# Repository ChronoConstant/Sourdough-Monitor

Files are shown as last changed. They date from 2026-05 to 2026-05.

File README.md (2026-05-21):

# Sourdough Monitor

A small battery-powered device that watches a sourdough starter rise after
feeding and reports to Home Assistant. It measures the height of the starter
with a time-of-flight sensor, tracks temperature and humidity, and lets you
mark feedings with a button press — so you can see, from your phone or a wall
dashboard, exactly how far along your starter is and when it peaked.

Built on a Seeed XIAO ESP32-C3 running [ESPHome](https://esphome.io/),
publishing over MQTT. Fair warning... I am dumb, Claude built most of this. So please take everything with a grain of LLM flavored salt. 

One small note about the enclosure. Obviously thats designed for a specific jar (Brod and Taylor) so it may or may not fit your project. Also I forgot to put a hole in it for a button. I drilled a hole for my button because I'm janky and didn't want to print it again. I'll update that eventually.

<!-- Add a photo of your build here, e.g.:
![Sourdough Monitor](docs/images/prototype.jpg)
-->

## What it does

- **Measures starter height** with a VL53L4CD time-of-flight sensor aimed down
  into the jar from a lid-mounted enclosure.
- **Tracks the fermentation environment** — temperature and humidity from an
  SHT31-D.
- **Computes rise %** relative to the post-feed baseline, and tracks the
  maximum rise reached in the current cycle.
- **"Just Fed" button** — a press marks a new feed cycle: it archives the
  previous cycle's stats, resets tracking, and re-establishes the baseline.
  Mirrored as a Home Assistant button so you can also trigger it from a phone.
- **Runs for weeks on a battery** — deep sleep between readings gets roughly a
  month per charge on a 1200 mAh LiPo.
- **Home Assistant integration** — all values auto-discover over MQTT. Includes
  a ready-made dashboard card and a peak-detection sensor.

## How it works

```
[SHT31-D]  temp/humidity ──┐
                           ├── I²C ── [XIAO ESP32-C3] ── Wi-Fi ── MQTT ── [Home Assistant]
[VL53L4CD] distance ───────┤
[Push button] "Just Fed" ──┘
```

The ESP32-C3 wakes every ~15 minutes, takes a reading, publishes it over MQTT,
and goes back to deep sleep. A button press also wakes it. Home Assistant
receives the data via MQTT discovery — entities appear automatically, no manual
HA configuration of the sensors required.

**Rise tracking**: when you long press (because the button wakes the board it requires a 2 second or so press to allow time for the board to wake up and realized you're pressing the button) "Just Fed", the firmware discards the old
baseline. The next sensor reading becomes the new baseline; subsequent readings
update it downward if the starter settles further. Once the starter starts
rising, the baseline locks and rise % is measured against it. This adaptive
approach means there's no fixed "settling delay" to guess at — the baseline
naturally finds the low point of the cycle.

## Bill of materials

| Part | Notes |
|---|---|
| **Seeed Studio XIAO ESP32-C3** | The MCU. Other ESP32-C3 boards can work but the pin map and the build guide assume the XIAO. |
| **VL53L4CD** time-of-flight sensor breakout | I²C. Measures the starter surface. A VL53L1X breakout also works — the driver supports both. |
| **SHT31-D** temperature/humidity breakout | I²C. Generic "SHT3x" breakouts work; see the troubleshooting doc re: the ADDR pin. |
| **Momentary push button** | Panel-mount, ~12 mm. The "Just Fed" input. |
| **LiPo battery, ~1200 mAh** | Single cell, 3.7 V, with a JST connector I snipped off to allow me to solder it to the board. The XIAO has onboard charging. |
| **2 × 100 kΩ resistors** | Optional — for the battery-voltage divider. Skip if you don't want battery monitoring. |
| **26–28 AWG wire** | Silicone-jacketed is easiest to work with. |
| **Tall straight-sided jar** | Weck / deli-quart style. Straight walls keep the rise math simple. |
| **3D-printed lid enclosure** | Holds everything; ToF aims down through a hole in the center. See [`enclosure/`](enclosure/). |

## Repository layout

```
.
├── README.md                  — this file
├── BUILD.md                   — step-by-step build & setup guide
├── LICENSE                    — GPLv3 (see "License" below)
├── firmware/
│   ├── sourdough.yaml          — the main ESPHome firmware
│   ├── sourdough-scan.yaml     — minimal I²C scanner for first bring-up
│   ├── secrets.yaml.example    — config template (copy to secrets.yaml)
│   └── components/vl53l1x/     — bundled ToF driver (third-party, see NOTICE)
├── homeassistant/
│   ├── lovelace-card.yaml      — dashboard card
│   └── peak-detection.yaml     — past-peak binary sensor + notification
├── enclosure/                  — 3D-printable lid STL files
└── docs/
    ├── wiring.md               — wiring guide
    └── troubleshooting.md      — common issues and fixes
```

## Quick start

Full instructions are in **[BUILD.md](BUILD.md)**. In short:

1. Wire the two I²C sensors and the button to the XIAO (see [`docs/wiring.md`](docs/wiring.md)).
2. Install [ESPHome](https://esphome.io/), copy `firmware/secrets.yaml.example`
   to `firmware/secrets.yaml`, and fill in your Wi-Fi and MQTT details.
3. Flash `firmware/sourdough.yaml` to the XIAO over USB.
4. The device's entities auto-appear in Home Assistant via MQTT discovery.
5. Calibrate the empty-jar distance, add the dashboard card, and you're done.

**Prerequisites**: Home Assistant with an MQTT broker (the Mosquitto add-on is
the usual choice).

## Home Assistant integration

Entities auto-discovered over MQTT include temperature, humidity, ToF distance,
starter height, rise %, max rise % this cycle, hours since feed, a battery
level, and the "Just Fed" button.

- [`homeassistant/lovelace-card.yaml`](homeassistant/lovelace-card.yaml) — a
  compact dashboard card (uses Mushroom + mini-graph-card from HACS).
- [`homeassistant/peak-detection.yaml`](homeassistant/peak-detection.yaml) — a
  template binary sensor that flips on when the starter has come off its peak,
  plus an example notification automation.

## Battery life

With deep sleep and a 15-minute wake interval, the device averages well under a
milliamp and runs roughly (hopefully?) **a month per charge** on a 1200 mAh LiPo. Charging is
over the XIAO's USB-C port. The optional resistor divider lets Home Assistant
display a battery percentage.

## Attribution

The VL53L4CD/VL53L1X driver in `firmware/components/vl53l1x/` is third-party
code from [Averyy/esphome-custom-components](https://github.com/Averyy/esphome-custom-components),
MIT licensed. It is bundled here (with a small i2c-API compatibility patch) so
the firmware builds reproducibly. See
[`firmware/components/vl53l1x/NOTICE`](firmware/components/vl53l1x/NOTICE) for
details of what was changed and why.

This project was developed with substantial help from Claude (Anthropic's AI
assistant) — firmware, and documentation.

## License

This project is licensed under the **GNU General Public License v3.0**. See the
`LICENSE` file. In short: you're free to use, modify, and distribute it, but
distributed derivatives must also be open-sourced under GPLv3.

The bundled `vl53l1x` component retains its original MIT license, which applies
to the files in that directory only. MIT is compatible with GPLv3.

## Contributing

Issues and pull requests welcome. If you build one, a photo and notes on what
you'd change are always appreciated.

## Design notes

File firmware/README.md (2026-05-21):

# firmware/

ESPHome firmware for the Sourdough Monitor.

| File | Purpose |
|---|---|
| `sourdough.yaml` | The main firmware — sensors, just-fed logic, deep sleep, MQTT. |
| `sourdough-scan.yaml` | Minimal I²C scanner. Flash first to verify sensor wiring. |
| `secrets.yaml.example` | Config template. Copy to `secrets.yaml` and fill in your values. |
| `components/vl53l1x/` | Bundled third-party ToF driver — see `components/vl53l1x/NOTICE`. |

**Full setup instructions — wiring, flashing, calibration, Home Assistant — are
in [`../BUILD.md`](../BUILD.md).**

Quick reference:

```bash
cp secrets.yaml.example secrets.yaml   # then edit secrets.yaml
esphome run sourdough-scan.yaml        # verify sensors respond on I²C
esphome run sourdough.yaml             # flash the real firmware
```

The first flash must be over USB; after that, `esphome run` updates over the
air. If the USB upload won't connect, put the XIAO in download mode: hold **B**,
tap **R**, release **B**, retry. More in
[`../docs/troubleshooting.md`](../docs/troubleshooting.md).

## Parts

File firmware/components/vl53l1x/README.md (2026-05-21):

# VL53L1X Component for ESPHome

This component provides integration with the VL53L1X/VL53L4CD Time-of-Flight (ToF) distance sensor for ESPHome using I2C. This implementation is an adaptation of existing open-source code that has been modified to enhance functionality and compatibility with ESPHome.

## Features

-   Supports both VL53L1X and VL53L4CD sensors
-   I2C communication
-   Configurable distance mode (short/long)
-   Configurable update interval
-   Range status reporting
-   Automatic sensor initialization and configuration

## Hardware Setup

Connect your VL53L1X/VL53L4CD sensor to your ESP32/ESP8266 using the following pins:

-   VL53L1X VCC → ESP32 3.3V
-   VL53L1X GND → ESP32 GND
-   VL53L1X SDA → ESP32 SDA (GPIO21 in example)
-   VL53L1X SCL → ESP32 SCL (GPIO22 in example)
-   VL53L1X XSHUT → ESP32 GPIO (GPIO23 in example, optional for power control)

## Configuration Variables

-   **distance_mode** (_Optional_, string, default: "long"): The distance mode of the sensor. Options are "short" or "long". Note that VL53L4CD sensors only support "short" mode and will be automatically configured as such.
-   **update_interval** (_Optional_, time, default: 0.5s): How often to update the sensor readings.
-   **i2c_id** (_Optional_, ID): The ID of the I2C bus if you have multiple I2C buses.

## Sensor Outputs

-   **distance**: Distance measurement in millimeters
-   **range_status**: Status of the range measurement (0 = valid, 1-4 = various error states), but I personally haven't gotten these to show up or be helpful

## Basic Configuration

```yaml
i2c:
    sda: GPIO21
    scl: GPIO22
    scan: true

# Optional XSHUT pin control
output:
    - platform: gpio
      pin: GPIO23
      id: xshut_pin

# Power on sequence
esphome:
    on_boot:
        then:
            - output.turn_on: xshut_pin
            - delay: 1s # Allow VL53L1X to boot (min 1.2ms required)
    on_shutdown:
        then:
            - output.turn_off: xshut_pin

vl53l1x:
    distance_mode: long
    update_interval: 0.5s

sensor:
    - platform: vl53l1x
      distance:
          name: "VL53L1X Distance"
          id: tof_distance
      range_status:
          name: "VL53L1X Range Status"
```

## Filtering Example

This example shows how to filter out invalid readings and apply a median filter to stabilize measurements:

```yaml
sensor:
    - platform: vl53l1x
      distance:
          name: "VL53L1X Distance"
          filters:
              - lambda: |-
                    if (x < 45 || x > 4200 || x == 0.0 || std::isnan(x)) {
                      return 0;
                    }
                    return x;
              - median:
                    window_size: 5
                    send_every: 5
                    send_first_at: 1
```

## Installation

There are two ways to install this component:

### Option 1: Direct from GitHub (Recommended)

Add the following to your ESPHome configuration:

```yaml
external_components:
    - source: github://Averyy/esphome-custom-components
      components: [vl53l1x]
```

**Note:** Using the GitHub repository version means you'll automatically get updates, but it could change at any moment. If stability is critical for your project, consider using the local installation method.

### Option 2: Local Installation

If you prefer a more stable setup or need to modify the component:

1. Create a `components` directory in your ESPHome configuration directory
2. Copy the `vl53l1x` directory into the `components` directory
3. Add the `external_components` section to your YAML configuration:

```yaml
external_components:
    - source: components
```

## Notes

-   The VL53L1X component automatically detects and configures the sensor on startup
-   The VL53L4CD sensor is automatically detected and forced to use "short" distance mode
-   The timing budget is set to 500ms for maximum accuracy
-   The sensor has a practical range of approximately 45mm to 4000mm
-   Readings outside this range or with invalid status should be filtered out
-   The sensor updates approximately every 90ms internally, regardless of the configured update interval

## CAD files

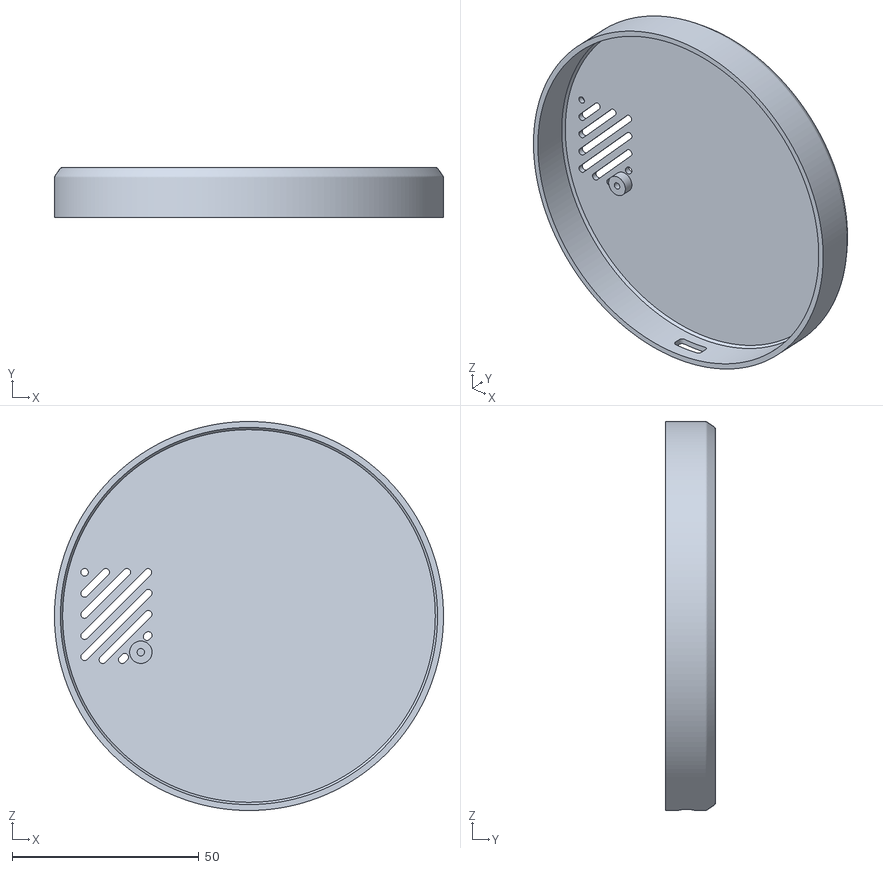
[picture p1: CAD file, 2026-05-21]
enclosure/Sourdough Lid Cover.stl
104.1 x 13.5 x 104.1

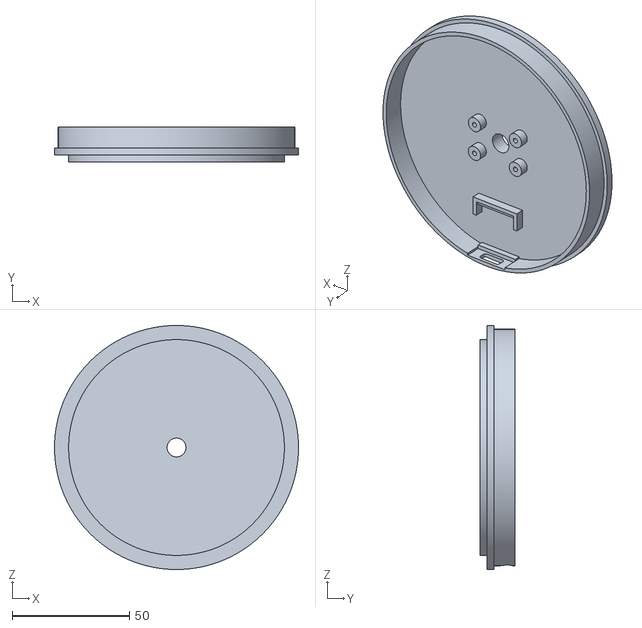
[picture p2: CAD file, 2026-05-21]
enclosure/Sourdough Lid Proto v2.stl
104.1 x 15.0 x 104.1

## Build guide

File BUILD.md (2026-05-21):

# Build Guide

Step-by-step instructions to build and set up a Sourdough Monitor. Plan on an
afternoon for the electronics and first flash, plus printing time for the
enclosure.

If something goes wrong, check [`docs/troubleshooting.md`](docs/troubleshooting.md)
first — most of the common snags are documented there with fixes.

---

## Before you start

You'll need:

- The parts in the [bill of materials](README.md#bill-of-materials).
- A **Home Assistant** instance with an **MQTT broker**. The
  [Mosquitto add-on](https://www.home-assistant.io/integrations/mqtt/) is the
  standard choice. If you don't have MQTT set up yet, do that first — the
  device has nowhere to publish to without it.
- A computer to run **ESPHome** (Windows, macOS, or Linux). The build guide
  uses the ESPHome command line.
- A **USB-C data cable** (not a charge-only cable) for the first flash.
- Basic soldering tools.

A note on skill level: this is an intermediate project. You don't need to be an
electronics expert, but you should be comfortable soldering small wires and
editing a YAML text file.

---

## Step 1 — Wiring

Full pin-by-pin detail is in [`docs/wiring.md`](docs/wiring.md). Summary:

| Connection | XIAO ESP32-C3 pin |
|---|---|
| Both sensors: VIN | `3V3` |
| Both sensors: GND | `GND` |
| Both sensors: SDA | `D4` (GPIO 6) |
| Both sensors: SCL | `D5` (GPIO 7) |
| Push button (one leg) | `D1` (GPIO 3) |
| Push button (other leg) | `GND` |
| LiPo battery | `BAT+` / `BAT−` pads (underside) |

Both I²C sensors share the same SDA and SCL wires — they have different
addresses (`0x44` and `0x29`) so they coexist on one bus. Most sensor breakouts
include their own pull-up resistors; don't add more.

For the **optional battery monitor**, wire a voltage divider — two 100 kΩ
resistors in series between `BAT+` and `GND`, with the midpoint going to
`D2` (GPIO 4). See Step 9.

**Tip**: before committing to soldered connections, build it on a breadboard
and confirm both sensors respond (Step 4). It's much easier to fix a wiring
mistake before everything is soldered into an enclosure.

---

## Step 2 — Install ESPHome

ESPHome needs **Python 3.10 or newer**. Check with `python3 --version`.

Install ESPHome (pipx keeps it cleanly isolated):

```bash
pip install pipx       # if you don't have pipx
pipx install esphome
```

Or with plain pip: `pip install esphome`.

Confirm it works: `esphome version`. You want a current release — if it
installs something old (2025.x or earlier), your Python is probably too old;
see [troubleshooting](docs/troubleshooting.md#esphome-installs-an-old-version).

---

## Step 3 — Configure your secrets

The firmware reads Wi-Fi and MQTT settings from a `secrets.yaml` file that you
create from the template.

```bash
cd firmware
cp secrets.yaml.example secrets.yaml
```

Open `secrets.yaml` and fill in your values. The file is commented with what
each one means. At minimum you need `wifi_ssid`, `wifi_password`,
`mqtt_broker`, and `ota_password`. Notes:

- The ESP32-C3 only does **2.4 GHz Wi-Fi** — it cannot see a 5 GHz network.
- The Wi-Fi SSID is **case-sensitive**.
- `mqtt_broker` is just the IP/hostname — **no `:1883` port suffix**.
- If your broker requires a login, set `mqtt_username` / `mqtt_password`. If
  it's anonymous, set them to empty strings (`""`).

### Optional: static IP

By default the device uses DHCP, which works on any network with zero extra
configuration — you can skip this entirely.

If you'd like a small battery-life improvement, you can give the device a
static IP. It saves the ~1–2 seconds of DHCP negotiation on every deep-sleep
wake. To enable it:

1. In `firmware/sourdough.yaml`, find the `wifi:` block and **uncomment the
   `manual_ip:` block** (remove the leading `#` from those five lines).
2. In `secrets.yaml`, **uncomment and fill in** the `static_ip`, `gateway`,
   `subnet`, and `dns1` values.
3. For `static_ip`, pick an address that's **outside your router's DHCP pool**
   (check the router's DHCP range), or reserve the address in your router by
   the device's MAC. This avoids the static IP colliding with an address the
   router might hand out to something else.
4. `gateway` is your router's IP, `subnet` is almost always `255.255.255.0`,
   and `dns1` is usually your router's IP.

Do this before flashing (Step 5). If you set it up later, just re-flash. And if
the device ever fails to connect after enabling it, the values almost certainly
don't match your network — comment the `manual_ip:` block back out to fall back
to DHCP.

---

## Step 4 — Verify the sensors (I²C scan)

Before flashing the full firmware, flash the minimal scanner config. This just
brings up the I²C bus and prints what it finds — a quick sanity check that your
wiring is correct.

```bash
esphome run sourdough-scan.yaml
```

For the **first flash you must use USB** (there's no firmware on the chip yet
for an over-the-air update). When prompted, choose the USB/serial device.

**macOS / Windows users**: if the upload fails to connect, you need to put the
XIAO into download mode manually — hold the **B** (Boot) button, tap **R**
(Reset), release **B**, then immediately retry. See
[troubleshooting](docs/troubleshooting.md#flashing-fails-to-connect-over-usb).

In the log output, you're looking for **both** sensor addresses:

```
Found i2c device at address 0x29   ← VL53L4CD
Found i2c device at address 0x44   ← SHT31-D
```

If only one shows up, fix the wiring before going further — the
[troubleshooting doc](docs/troubleshooting.md#only-one-i2c-sensor-shows-up) has
a checklist.

---

## Step 5 — Flash the firmware

Once both sensors scan cleanly, flash the real firmware:

```bash
esphome run sourdough.yaml
```

Same as before — USB for this first flash, BOOT/RESET dance if it won't
connect. The compile takes a few minutes the first time (it downloads
toolchains and builds the bundled component).

After this first USB flash, **future updates can be done wirelessly** — run the
same command and pick the network/OTA option.

> **Path gotcha**: ESP-IDF cannot build from a path containing spaces. If your
> project folder has spaces in its name, the build fails with "Detected a
> whitespace character in project paths." Rename the folder to use underscores
> or dashes. (See [troubleshooting](docs/troubleshooting.md#build-fails-on-whitespace-in-path).)

---

## Step 6 — Confirm entities in Home Assistant

The firmware publishes over MQTT with discovery enabled, so Home Assistant
picks up the device automatically. Within a minute or two of the device's first
boot, go to **Settings → Devices & Services → MQTT** and you should see a
"Sourdough Monitor" device with entities: Temperature, Humidity, ToF Distance,
Starter Height, Rise %, Max Rise % This Cycle, Hours Since Feed, Battery
Voltage / Level, and a "Just Fed" button.

If nothing appears, check the device log (`esphome logs sourdough.yaml`) for
the Wi-Fi and MQTT connection lines.

---

## Step 7 — Calibrate the empty-jar distance

The firmware needs to know the distance from the sensor down to the bottom of
the empty jar (`d_empty`) to compute starter height.

1. Put a small piece of **white paper** flat in the bottom of the **empty**
   jar. (Glass and clear plastic can be partly transparent to the sensor's
   infrared — the paper gives it a clean surface to range against.)
2. Put the lid/enclosure on the jar in its normal position.
3. Watch the **ToF Distance** entity in Home Assistant. Let it report a few
   readings and note the stable value (in mm).
4. In Home Assistant, find the **Empty Jar Distance (mm)** number entity and
   set it to that value.

That's it. The starter-height and rise-% math now have their reference point.
If you ever change how the lid sits on the jar or use a new jar, redo this.

---

## Step 8 — Add the dashboard card

[`homeassistant/lovelace-card.yaml`](homeassistant/lovelace-card.yaml) is a
compact card for a Home Assistant dashboard. It uses two cards from
[HACS](https://hacs.xyz/): **Mushroom** and **mini-graph-card** — install those
first.

Then, on a dashboard: **Edit → Add Card → Manual**, and paste in the contents
of `lovelace-card.yaml`. If your device entities have different IDs than the
defaults, adjust the entity names in the card (they're all near the top of each
section).

---

## Step 9 — Battery monitoring (optional)

If you wired the voltage divider (Step 1), the **Battery Voltage** and
**Battery Level** entities will show real values. If you didn't, those entities
just report nonsense — harmless, ignore them or remove the `adc` and battery
`template` sensors from `sourdough.yaml`.

To verify the divider: with the device powered, measure between `D2` (GPIO 4)
and `GND` — it should read about half the battery voltage.

---

## Step 10 — Peak detection (optional)

[`homeassistant/peak-detection.yaml`](homeassistant/peak-detection.yaml)
contains a Home Assistant template binary sensor that flips on when the starter
has come off its peak, plus an example notification automation. The file is
commented with where each piece goes in your HA config and what to tune. It's
optional — the monitor is fully usable without it.

---

## Using it day to day

**To mark a feeding**: Push the button before removing the lid to avoid a crazy reading when you set it aside. feed the starter, put the lid back on the jar, and
press the button. (If the device is asleep, hold the button for about a second or two
so the press registers as it wakes up.)

What happens: the previous cycle's stats get archived, rise tracking resets, and
"Rise %" shows 0 until the next sensor reading establishes the new
baseline — up to ~15 minutes later. After that, watch the rise climb.

**Charging**: plug a USB-C cable into the XIAO. With deep sleep the battery
lasts about a month, so this is infrequent.

---

## Updating the firmware later

After the first USB flash, the device accepts over-the-air updates. Edit
`sourdough.yaml`, then:

```bash
esphome run sourdough.yaml
```

Choose the network/OTA option when prompted.

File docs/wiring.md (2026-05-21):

# Wiring

**Board:** Seeed XIAO ESP32-C3.

## Pin assignments

| XIAO pin | GPIO | Role | Notes |
|---|---|---|---|
| D4 (SDA) | GPIO 6 | I²C SDA | Silkscreen-labeled SDA; clean GPIO (not strapping, not USB, not flash) |
| D5 (SCL) | GPIO 7 | I²C SCL | Silkscreen-labeled SCL |
| D1 | GPIO 3 | Push button | Active low, internal pull-up enabled in firmware |
| D2 | GPIO 4 | Battery ADC (optional) | Reads the midpoint of the BAT+/GND voltage divider; see [Battery monitoring](#battery-monitoring-optional) |
| 3V3 | — | Sensor power | Do NOT use the 5V pin — both sensors run fine at 3.3 V |
| GND | — | Common ground | |

Free for later use: D0 (GPIO 2, strapping — OK as output), D3 (GPIO 5), D6 (GPIO 21, UART TX), D7 (GPIO 20, UART RX), D8 (GPIO 8, strapping), D10 (GPIO 10). **Avoid** D9 (GPIO 9) — that's the BOOT strapping pin.

## Why these pins
- **SDA/SCL on D4/D5** — matches the XIAO silkscreen, keeps documentation honest, and both are clean GPIOs with no special-function conflicts.
- **Button on D1** — any "safe" GPIO works; D1 puts it adjacent to the GND pin on the header for a clean two-wire run.
- **Battery sense on D2** — must be an ADC-capable pin; the ESP32-C3's ADC1 channels are on GPIO 0–4, and D2/GPIO 4 is otherwise free.

## Sensor hookup

Both breakouts (Adafruit/SparkFun-style; verify your specific boards):

| SHT31-D pin | VL53L4CD pin | XIAO pin |
|---|---|---|
| Vin / 3V | Vin / VCC | 3V3 |
| GND | GND | GND |
| SDA | SDA | D4 (GPIO 6) |
| SCL | SCL | D5 (GPIO 7) |

Sensor SDA lines share a single wire; sensor SCL lines share a single wire. The two breakouts have different I²C addresses (`0x44` and `0x29`) so they don't collide on the shared bus. Both breakouts include onboard 10 kΩ pull-ups — **don't add extras**; two in parallel already gives ~5 kΩ, which is on the strong side.

## Battery monitoring (optional)

The XIAO's ADC can't read the LiPo voltage directly — a charged cell sits above
the 3.3 V the ADC can measure, and there's no internal divider on the board. To
monitor the battery, add an external voltage divider: two equal resistors
between BAT+ and GND, with the midpoint feeding an ADC pin.

```
BAT+ ──┬── 100 kΩ ──┬── 100 kΩ ── GND
       │            │
   (battery)        └── to D2 (GPIO 4)
```

The midpoint sits at half the battery voltage — roughly 1.9 V at a 3.7 V cell,
2.1 V at a full 4.2 V — comfortably inside the ADC's range. The firmware doubles
the reading back to actual battery voltage and estimates a percentage from it.

Notes:
- **100 kΩ each** is the recommended value. The divider draws current
  continuously (battery voltage ÷ 200 kΩ ≈ 19 µA) — negligible. Much lower
  values waste battery; much higher values make the ADC reading noisy.
- The bottom resistor can connect to GND or directly to the LiPo's BAT−
  terminal — they're the same node.
- This is **optional**. Skip it and the firmware's battery sensors just report
  meaningless values, which is harmless — ignore or delete those entities.

## Breadboard layout

```
        XIAO ESP32-C3
        ┌─────────────┐
USB-C ─→│             │
        │  5V         │
        │  GND ───────┼──── breadboard GND rail
        │  3V3 ───────┼──── breadboard 3V3 rail
        │  D0/GPIO2   │
        │  D1/GPIO3 ──┼──── button ── GND
        │  D2/GPIO4 ──┼──── battery divider midpoint (optional)
        │  D3/GPIO5   │
        │  D4/GPIO6 ──┼──── SDA bus ──── SHT31-D SDA, VL53L4CD SDA
        │  D5/GPIO7 ──┼──── SCL bus ──── SHT31-D SCL, VL53L4CD SCL
        │  D6/GPIO21  │
        │  D7/GPIO20  │
        │  D8/GPIO8   │
        │  D9/GPIO9   │  ← avoid (BOOT strapping)
        │  D10/GPIO10 │
        └─────────────┘

SHT31-D:   Vin→3V3 rail, GND→GND rail, SDA→SDA bus, SCL→SCL bus
VL53L4CD:  Vin→3V3 rail, GND→GND rail, SDA→SDA bus, SCL→SCL bus
Button:    one leg → D1, other leg → GND   (firmware enables INPUT_PULLUP)
Battery:   BAT+ → 100kΩ → D2 → 100kΩ → GND   (optional; see Battery monitoring)
```

## Power notes

- USB-C from the XIAO powers the device and charges the LiPo.
- The LiPo solders to the BAT+ / BAT− pads on the XIAO's underside. The XIAO has onboard charge management — plug in USB to charge, run on battery when unplugged.
- Wi-Fi antenna is integrated. A U.FL connector is available for an external antenna if Wi-Fi signal is weak where the device lives.

## After wiring: the I²C scan

Before flashing the full firmware, flash the minimal `sourdough-scan.yaml` config (just the `i2c:` block with `scan: true`). The boot log should list two devices:

```
[I][i2c.idf:170]: Found i2c device at address 0x29   ← VL53L4CD
[I][i2c.idf:170]: Found i2c device at address 0x44   ← SHT31-D
```

If you see only one address, the most likely culprits, in order:
1. A loose wire on SDA or SCL to the missing sensor.
2. The missing sensor's Vin is not actually getting 3.3 V (check with a multimeter against GND).
3. SDA/SCL swapped at one of the breakouts.
4. (Rare) the breakout has a non-default ADDR jumper soldered, putting the sensor on `0x45` or `0x52` instead. Reflow if so.

Once both addresses scan cleanly, the wiring is verified — flash the full firmware (`sourdough.yaml`).

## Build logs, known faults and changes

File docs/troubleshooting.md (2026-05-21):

# Troubleshooting

Every issue here was hit during the development of this project. If you run
into something, there's a decent chance the answer is below.

---

## Sensors and wiring

### Only one I2C sensor shows up

The I²C scan finds one address but not the other (you want both `0x29` for the
VL53L4CD and `0x44` for the SHT31-D).

Check, in order:

1. **A loose wire** to the missing sensor — SDA, SCL, VIN, or GND. With the
   device powered, measure each pin on the missing sensor's breakout against
   GND: VIN should read ~3.3 V, SDA and SCL should idle near 3.3 V.
2. **SDA/SCL swapped** at the missing breakout.
3. **The chip is simply dead.** Cheap sensor breakouts have a high failure
   rate. Also sometimes you might get a counterfeit off amazon. If power, ground, and both bus lines measure correct at the breakout
   and it still doesn't answer at any address, replace it. (This happened to
   me — the first SHT31-D was dead on arrival despite perfect wiring.)

---

## ESPHome and flashing

### `vl53l4cd` / `vl53l1x` platform not found

The VL53L4CD is **not in ESPHome core**. This project bundles a working driver
in `firmware/components/vl53l1x/` and the firmware references it via a local
`external_components` entry — so a normal build just works.

If you ever swap in the upstream component fresh from
[Averyy/esphome-custom-components](https://github.com/Averyy/esphome-custom-components)
and the build fails with errors like *"candidate expects 3 arguments, 4
provided"* on `write_register16` / `read_register16` — that's an ESPHome i2c
API change the upstream hasn't caught up with. The fix is the patch already
applied to the bundled copy: remove the 4th argument (a `true`/`false`) from
those five calls. See `firmware/components/vl53l1x/NOTICE`.

### ESPHome installs an old version

If `esphome version` reports an old release (2025.x or earlier), your Python is
too old. ESPHome needs **Python 3.10+**; older Python silently pins ESPHome to
its last compatible release. Check `python3 --version`. On macOS the system
Python is often 3.9 — install a newer one (e.g. `brew install python@3.12`) and
reinstall ESPHome.

### Build fails on whitespace in path

Error: *"Detected a whitespace character in project paths."* ESP-IDF's build
system cannot handle spaces anywhere in the path to the project. Rename the
project folder (and any parent folders) to use underscores or dashes instead
of spaces, then rebuild.

### Flashing fails to connect over USB

Symptom: `Failed to connect to ESP32-C3: Wrong boot mode detected` or the
upload just times out. macOS especially struggles to auto-reset the XIAO into
download mode.

Fix — put the chip into download mode manually:

1. Hold down the **B** (Boot) button on the XIAO.
2. While holding B, tap the **R** (Reset) button and release it.
3. Release B.
4. Immediately re-run the flash command.

The chip is now in the ROM bootloader and esptool can connect reliably.

---

## Firmware behavior

### Rise % reads 0 for a while after a feed

Expected. After a "Just Fed" press the baseline is discarded; the next sensor
reading (up to one ~15-minute wake cycle away) establishes the new baseline.
Until then Rise % reads 0 — there is no baseline to measure against yet. Once
the new baseline is set, it starts climbing normally.

### Battery Voltage / Battery Level show nonsense

Those entities only mean something if you wired the optional voltage divider
(two 100 kΩ resistors, BAT+ → divider → GPIO 4 → GND). Without it, GPIO 4
floats and the readings are garbage. Either wire the divider or delete the
`adc` and battery `template` sensors from `sourdough.yaml`.

---

## Home Assistant

### Distance shows in inches instead of mm

Home Assistant auto-converts the display units of any sensor with a
`device_class` of `distance`, based on your account's unit system. This
firmware sets `device_class: ""` on the distance-type sensors specifically to
suppress that conversion. If you see inches anyway, confirm those `device_class:
""` lines are present, or switch your HA unit system to metric.

### Entities don't appear in Home Assistant

- Confirm the device actually connected to Wi-Fi and MQTT — check
  `esphome logs sourdough.yaml`.
- Confirm Home Assistant's MQTT integration is set up and pointed at the same
  broker.
- The MQTT discovery prefix must match (`homeassistant`, the default on both
  sides).

### Device shows "unavailable" in HA between readings

By default this firmware disables MQTT birth/will messages (see the `mqtt:`
block), specifically so HA does *not* mark everything unavailable each time the
chip sleeps. If you re-enable them, HA will flip every entity to "unavailable"
for the ~15 minutes between wakes. That's the trade-off — the device genuinely
is offline while asleep.

---

## Networking

### Device won't connect to Wi-Fi

- The ESP32-C3 is **2.4 GHz only**. It cannot see a 5 GHz network, even if your
  router shares one name across both bands (it'll just use the 2.4 GHz one — but
  confirm 2.4 GHz is enabled).
- The SSID is **case-sensitive**. `MyNetwork` and `mynetwork` are different
  networks. Copy it exactly.

### MQTT won't connect — "Couldn't resolve IP address"

The `mqtt_broker` value in `secrets.yaml` must be the address **only** — no
port. `192.168.1.10`, not `192.168.1.10:1883`. The port is configured
separately (and defaults to 1883).

### MQTT won't connect — "Connection refused, error 0x5"

That's MQTT's "Not Authorized" code — the broker rejected the login. The Home
Assistant Mosquitto add-on does **not** allow anonymous connections by default.
Create a Home Assistant user for the device and put those credentials in
`secrets.yaml` as `mqtt_username` / `mqtt_password`.

### Router shows the device connected for ~5 minutes after it sleeps

Cosmetic, not a real problem. When the ESP32-C3 enters deep sleep it powers the
Wi-Fi radio off without sending a clean disassociation frame, so the router
doesn't notice immediately and prunes the device on its own inactivity timeout
(often ~5 minutes). The device really is asleep and saving power — the router's
connected-devices list is just stale. Ground truth is the deep-sleep log line
and the battery drain rate.

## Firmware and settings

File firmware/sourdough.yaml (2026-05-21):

# sourdough.yaml — firmware for the Sourdough Monitor.
#
# Hardware: Seeed XIAO ESP32-C3 + SHT31-D + VL53L4CD + push button on D1.
# See README.md and docs/wiring.md for the full picture.
#
# What this firmware does:
#   - Deep-sleeps between wakes; wakes every ~15 min (or on a button
#     press) to read sensors, publish over MQTT, and sleep again.
#   - Reads temperature/humidity from the SHT31-D and ToF distance from
#     the VL53L4CD.
#   - Computes starter_height_mm and rise_pct as derived sensors, and
#     tracks max rise % and average temp/RH over the current feed cycle.
#   - On Just-Fed press (physical button OR HA button):
#       * Publishes the prior cycle's stats to sourdough/<jar>/cycle_complete
#       * Resets per-cycle state and the rise baseline
#       * Stamps the last-fed timestamp
#     The new baseline is established adaptively afterwards: the next
#     reading sets it, then it tracks down to the cycle's low point.
#   - Exposes d_empty as an HA number entity for calibration.
#   - Auto-discovers all entities in HA via MQTT discovery.

substitutions:
  device_name: sourdough
  friendly_name: Sourdough Monitor
  jar_id: jar1                  # change if running multiple jars in the future
  # With deep_sleep enabled, the cadence the *user* cares about (how often
  # data lands in HA) is sleep_duration. Sensor update_interval just needs
  # to be short enough that they actually fire during the run_duration
  # wake window — otherwise they'd never poll.
  update_interval: 10s          # in-wake sensor polling — fires within run_duration
  run_duration: 15s             # awake time per wake cycle (Wi-Fi connect + reads + publish)
  sleep_duration: 15min         # how often the chip wakes for a periodic read

esphome:
  name: ${device_name}
  friendly_name: ${friendly_name}
  on_boot:
    priority: -100
    then:
      - logger.log: "Sourdough monitor booted."
      # If the chip woke up because the button was pressed (vs. periodic
      # timer wake), execute the just-fed action. The binary_sensor's
      # on_press may miss the press because the pin can transition high
      # again before the binary_sensor finishes initializing after deep
      # sleep. This catches the "button still held at boot" case as a
      # safety net. User should hold the button for ~1 second when waking
      # the device to ensure the press is captured.
      - delay: 250ms
      - if:
          condition:
            binary_sensor.is_on: just_fed_button
          then:
            - logger.log: "Wake-from-button detected at boot; firing just-fed action."
            - script.execute: just_fed_action

esp32:
  board: esp32-c3-devkitm-1
  variant: ESP32C3
  framework:
    type: esp-idf

logger:
  level: DEBUG
  hardware_uart: USB_SERIAL_JTAG

wifi:
  ssid: !secret wifi_ssid
  password: !secret wifi_password
  # fast_connect skips the Wi-Fi scan phase, speeding up reconnect after
  # each deep-sleep wake. Works on any network — safe to leave on.
  fast_connect: true

  # OPTIONAL — static IP. Saves ~1-2 seconds of DHCP negotiation per wake,
  # which modestly improves battery life (~15-20% longer between charges).
  # NOT required — with this block commented out the device uses DHCP and
  # works on any network with zero configuration.
  #
  # To enable: uncomment the block below, and set the four matching values
  # in secrets.yaml to fit YOUR network. Pick a static_ip outside your
  # router's DHCP pool (or reserve it in the router by MAC address).
  #
  # manual_ip:
  #   static_ip: !secret static_ip
  #   gateway: !secret gateway
  #   subnet: !secret subnet
  #   dns1: !secret dns1

mqtt:
  broker: !secret mqtt_broker
  # MQTT credentials. If your broker requires auth (the HA Mosquitto add-on
  # does by default), set these in secrets.yaml. If your broker allows
  # anonymous connections, set both to empty strings ("") in secrets.yaml —
  # or, if empty strings still get rejected, comment these two lines out.
  username: !secret mqtt_username
  password: !secret mqtt_password
  topic_prefix: sourdough/${jar_id}
  discovery: true
  discovery_prefix: homeassistant
  # Disable birth and will messages — with deep sleep, the chip is
  # intentionally "offline" most of the time. Without these, HA's
  # discovery omits the availability topic, and HA shows the last known
  # value indefinitely instead of flipping every entity to "Unknown"
  # the instant the chip sleeps.
  #
  # Trade-off: if the device actually dies, HA won't know — values stay
  # at their last reported state. Mitigation, if you want it later: a
  # template sensor that flags the device "stale" if no sensor has
  # updated for >2 × sleep_duration.
  birth_message:
  will_message:

ota:
  - platform: esphome
    password: !secret ota_password
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
